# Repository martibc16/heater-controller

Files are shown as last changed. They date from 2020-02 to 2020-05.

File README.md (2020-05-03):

# heater-controller
A project to controll a domestic heating system with central heating and DHW

The heating system at home was initially controlled with simple relays that where commanded by thermostats. This had the problem that the integrated circulating pump would be on even the thermostats where off and so the actuators (that cut the flow of water to the circuit) where off. This is a picture of the heating room before:

<p align="center">
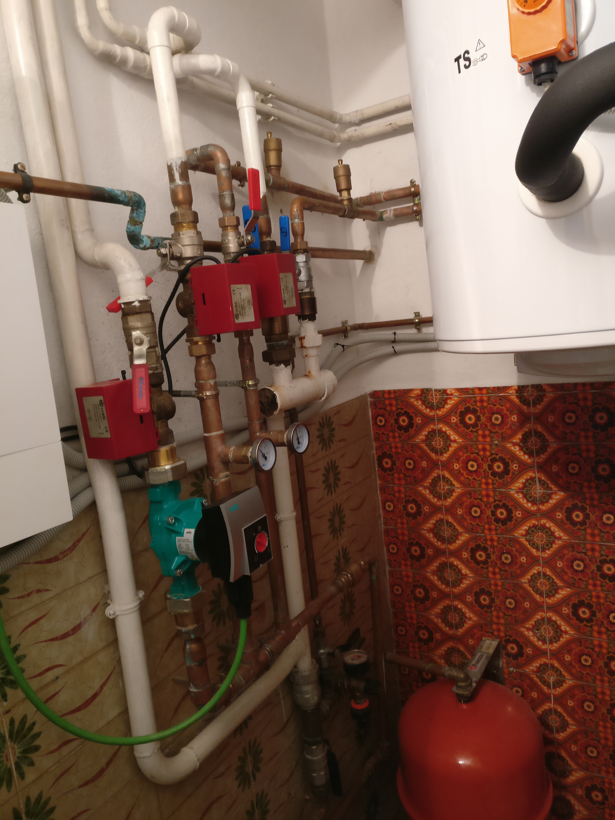
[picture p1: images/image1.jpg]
  
</p>

The controller is mounted on a DIN box and integrated in the electric panel.

The controller has:
* 6 optoisolated  digital outputs for connecting external relays
* 6 pull-down inputs
* I2C interface
* DS3231 RTC
* Atmega 2560 MCU

The result is this PCB:

<p align="center">
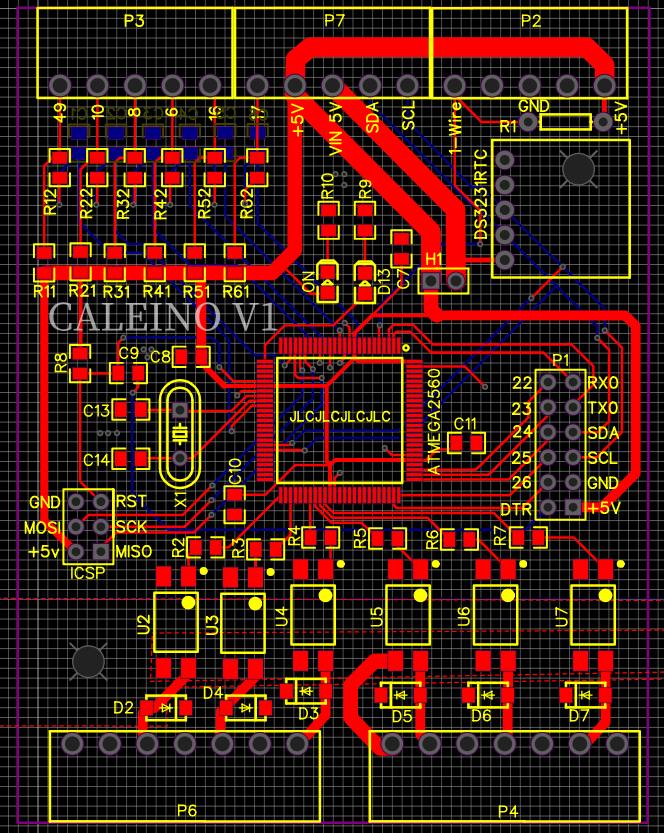
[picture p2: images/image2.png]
  
</p>
<p align="center">
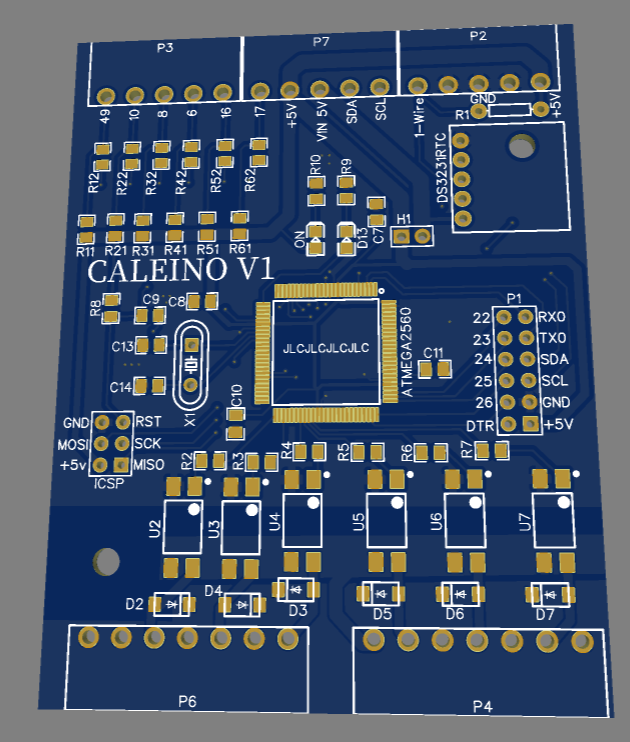
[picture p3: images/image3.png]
  
</p>

The analog temperature indicators were replaced by 1-wire sensors. To acomodate these sensors on the existing housing a 3D piece was needed to avoid the sensor being loose. This is a preview of the model:

<p align="center">
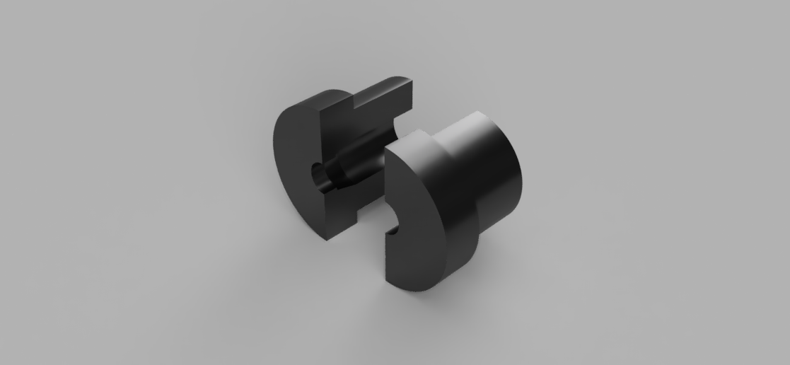
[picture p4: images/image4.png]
  
</p>
And this is the result when mounted with the sensor:
<p align="center">
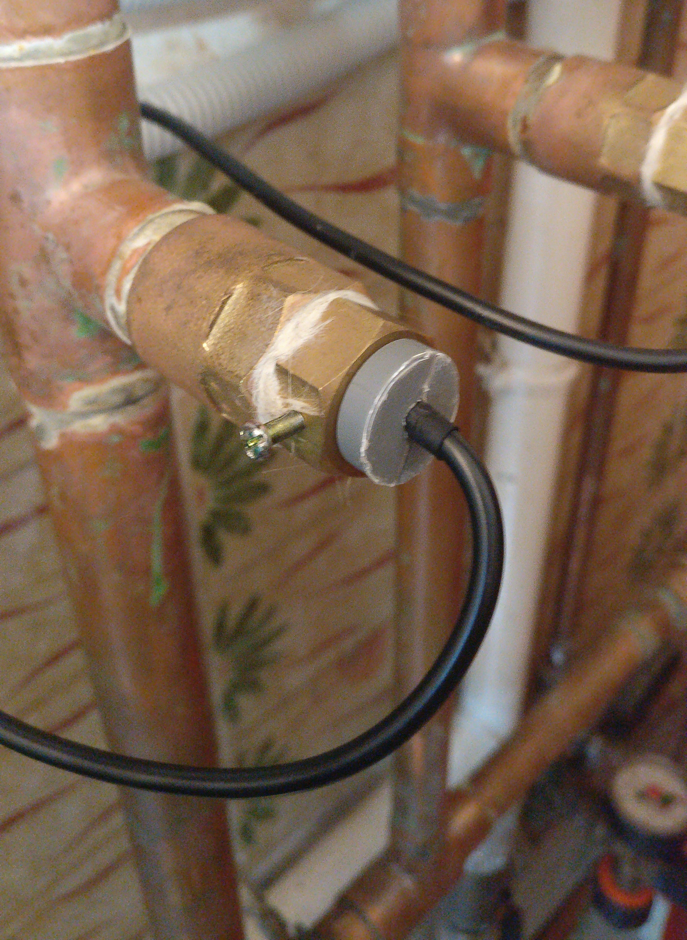
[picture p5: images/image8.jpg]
  
</p>

Finally, this is the photo of the finished model. Apart from the main PCB an auxiliary board has been created to acomodate the screen, the buttons and the programming interface (via FTDI connector). Through the screen you can control the status of the DHW supply (temperature and programmed state). It also gives information on the temperature of the DHW tank and the water temperature of the primary circuit (these are the sensors that are mounted with the 3D piece).
<p align="center">
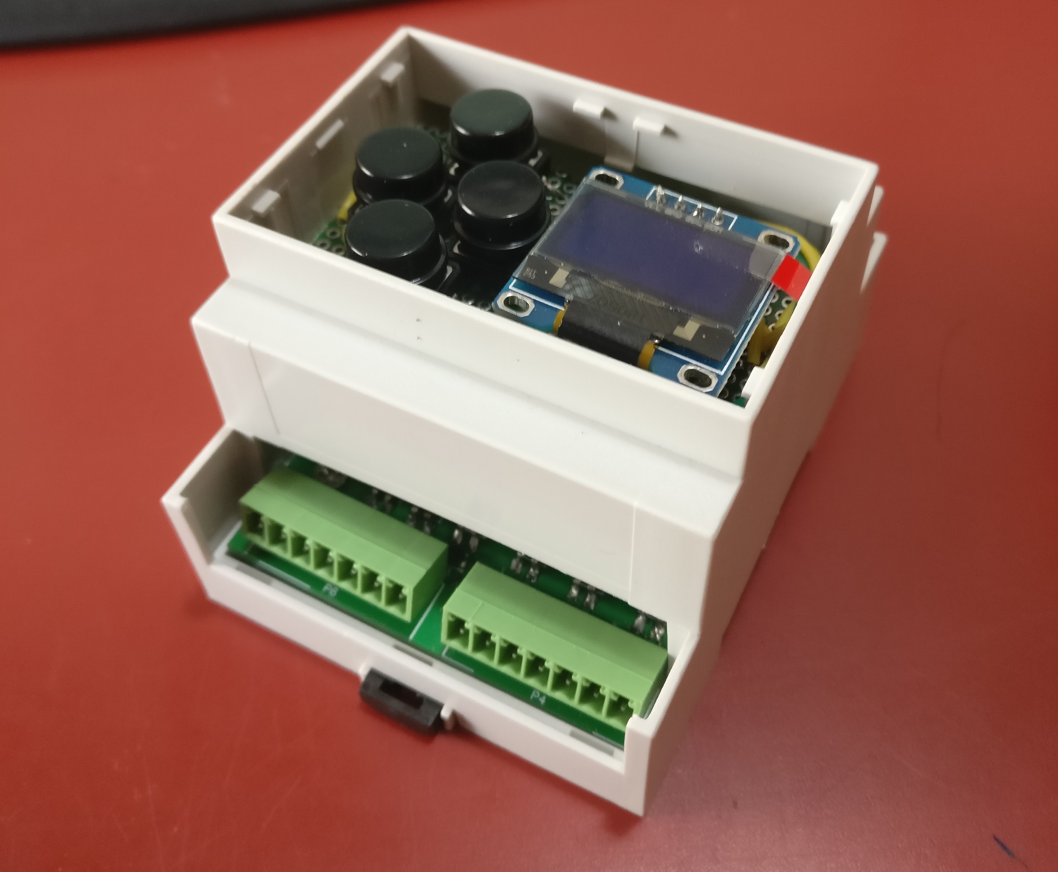
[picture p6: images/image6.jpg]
  
</p>
<p align="center">
  
</p>

The controller recieves the inputs from the thermostat on the dinning room (it's a normally open contact), the DHW tank temperature and the fireplace located on the dinning room (this is precisely the purpose of the green pump: To circulate the water from the fireplace into the main system) and the actuates on the ouputs which are connected to DIN relays. This gives the safest scenario since only the relays controll AC mains, the whole PCB works with low voltage DC (between 5V and 12V).

Here is a photo of the screen's controller:
<p align="center">
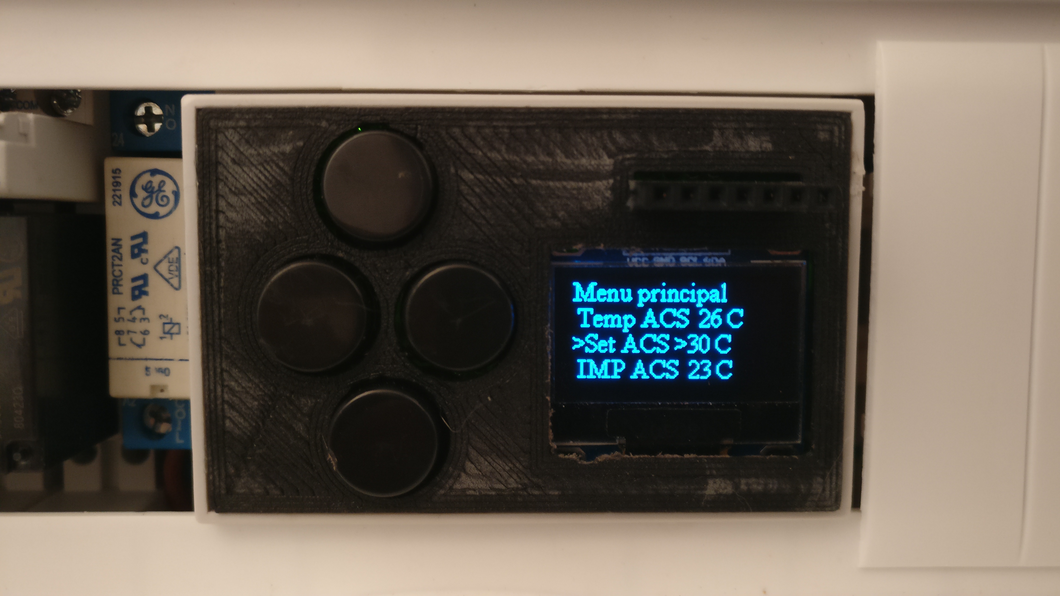
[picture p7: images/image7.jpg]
  
</p>

The programming was made using the Arduino IDE (See code folder)
The 3d model of the wire holder and the screen cover were made using Fusion360
The schematic and PCB files were made using EasyEDA software: https://easyeda.com/603mbastida/caleino-v4

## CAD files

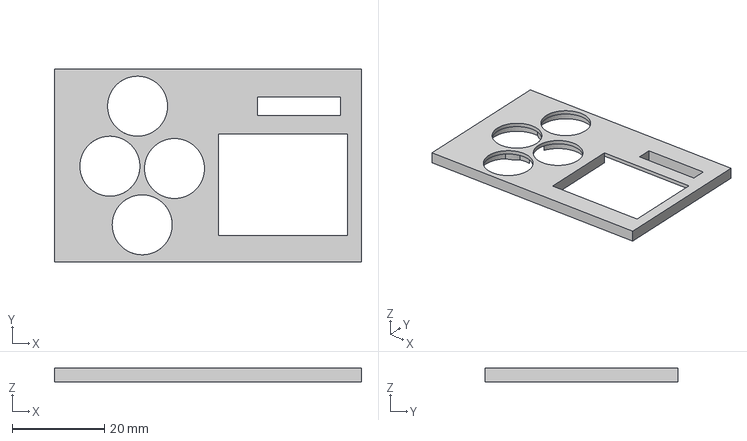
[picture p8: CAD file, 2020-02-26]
3d models/frontal_cover.step
66.5 x 41.7 x 3.00 mm

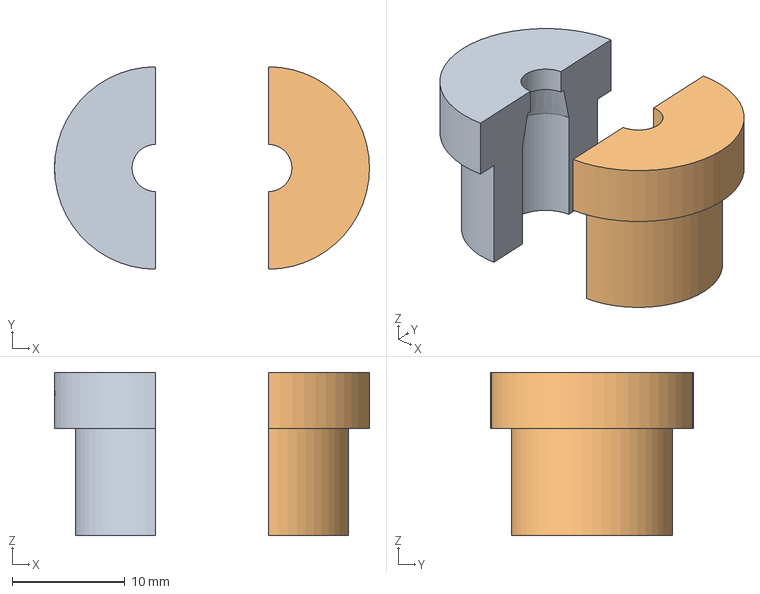
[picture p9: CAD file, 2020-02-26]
3d models/sensor_housing.step
28.0 x 18.0 x 14.5 mm

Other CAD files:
3d models/frontal_cover.f3d
3d models/sensor_housing.f3d

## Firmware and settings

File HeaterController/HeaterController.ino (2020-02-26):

#include "config.h"
#include "Menu.h"
#include "LogicaCale.h"


void setup() {
  Serial.begin(9600);

  EEPROM.get(0, tSetACS);
  EEPROM.get(20, deltaT);
  refreshEeprom = millis();

  if (tSetACS > 80)
    tSetACS = 45;

  if (deltaT > 20)
    deltaT = 4;

  setSyncProvider(RTC.get);   // the function to get the time from the RTC
  if (timeStatus() != timeSet)
    Serial.println("Unable to sync with the RTC");
  else
    Serial.println("RTC has set the system time");

  pinMode(PINACS, OUTPUT);
  pinMode(PINCALE, OUTPUT);
  pinMode(PINFAT, OUTPUT);
  pinMode(PINCALDERA, OUTPUT);
  pinMode(PINTERMOSTAT, INPUT_PULLUP);
  pinMode(PINBOMBACIR, INPUT_PULLUP);
  pinMode(PINTERMOFAT, INPUT_PULLUP);
  pinMode(A6, INPUT);
  termostatActiu = false;
  canviEstat = false;
  ACSON = false;

  sensors.begin();
  sensors.setResolution(ACS, resolution);

  sensors.setWaitForConversion(false);
  sensors.requestTemperatures();

  delayInMillis = 750 / (1 << (12 - resolution));
  lastTempRequest = millis();

  
    Alarm.alarmRepeat(10, 0, 0, onProg);
    Alarm.alarmRepeat(13, 30, 0, offProg);
    Alarm.alarmRepeat(dowMonday , 16, 0, 0, onProg);
    Alarm.alarmRepeat(dowTuesday , 16, 0, 0, onProg);
    Alarm.alarmRepeat(dowWednesday , 16, 0, 0, onProg);
    Alarm.alarmRepeat(dowThursday , 16, 0, 0, onProg);
    Alarm.alarmRepeat(dowFriday , 16, 0, 0, onProg);
    Alarm.alarmRepeat(dowSaturday , 16, 0, 0, onProg);
    Alarm.alarmRepeat(19, 30, 0, offProg);
    Alarm.alarmRepeat(23, 0, 0, offProg);
  
 // newAlarm(9, 30, 1, true);


  joystickBtns.begin();
  Wire.begin();
  oled.begin(&Adafruit128x64, OLED_I2C_ADDRESS); //check config
  oled.setFont(menuFont);
  oled.clear();
  tempsStandby = millis();

#if RST_PIN >= 0
  oled.begin(&Adafruit128x64, I2C_ADDRESS, RST_PIN);
#else // RST_PIN >= 0
  oled.begin(&Adafruit128x64, I2C_ADDRESS);
#endif // RST_PIN >= 0


  mainMenu[0].disable();
  mainMenu[2].disable();
  mainMenu[3].disable();
  mainMenu[5].disable();

  Wire.setClock(400000);
}

float timre;
void loop() {
  timre = millis();
  readSensors();

  storeInEEPROM();

  checkForStateChanges();

  nav.poll();
  Alarm.delay(1);//simulate a delay when other tasks are done

  /**********Used for debugging************/
  /*Serial.print(hour());
    Serial.print("\t");
    Serial.print(minute());
    Serial.print("\t");
    Serial.print(second());
    Serial.print("\t");*/
    Serial.print(progACS);
    Serial.print("\t AutoProg:");
    Serial.print(autoProgACS);
    Serial.print("\t tACS: ");
    Serial.print(tACS);
    Serial.print("\t");
    Serial.print(tSetACS);
    Serial.print("\t");
    Serial.print(tSetACS+deltaT);
    Serial.print("\t ACSon:");
    Serial.println(ACSON);
  /**********************/


  if (digitalRead(BTN_SEL) == LOW || digitalRead(BTN_UP) == LOW || digitalRead(BTN_DOWN) == LOW || digitalRead(BTN_ESC) == LOW)
  {
    tempsActiu = millis();
    oled.ssd1306WriteCmd(SSD1306_DISPLAYON);
  }
  else if (millis() - tempsActiu > 60000)
    oled.ssd1306WriteCmd(SSD1306_DISPLAYOFF);

}

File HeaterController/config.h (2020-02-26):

/*config.h*/

/* List of Supported Fonts

  Arial14,
  Arial_bold_14,
  Callibri11,
  Callibri11_bold,
  Callibri11_italic,
  Callibri15,
  Corsiva_12,
  fixed_bold10x15,
  font5x7,    //Do not use in LARGE_FONT, can use as default font
  font8x8,
  Iain5x7,    //Do not use in LARGE_FONT, can use as default font
  lcd5x7,     //Do not use in LARGE_FONT, can use as default font
  Stang5x7,   //Do not use in LARGE_FONT, can use as default font
  System5x7,  //Do not use in LARGE_FONT, can use as default font
  TimesNewRoman16,
  TimesNewRoman16_bold,
  TimesNewRoman16_italic,
  utf8font10x16,
  Verdana12,
  Verdana12_bold,
  Verdana12_italic,
  X11fixed7x14,
  X11fixed7x14B,
  ZevvPeep8x16

*/


/*
   Incloem llibreries
*/

#include <menu.h>

#include <EEPROM.h>

#include <TimeLib.h>
#include <TimeAlarms.h>
#include <DS3232RTC.h>

#include <OneWire.h>
#include <DallasTemperature.h>
#include <Wire.h>

#include "SSD1306Ascii.h"
#include "SSD1306AsciiWire.h"
#include <menu.h>
#include <menuIO/SSD1306AsciiOut.h>
#include <menuIO/keyIn.h>


/*
   Definim sortides a optoacopladors
*/
#define PINACS 33
#define PINCALE 37
#define PINFAT 32 //actuador Foc a Terra
#define PINCALDERA 41

/*
 * Definim entrades digitals
 */
#define PINTERMOSTAT 49
#define PINBOMBACIR 8
#define PINTERMOFAT 10


/*
   Definim variables calefaccio
*/
 short int tACS ;
unsigned short int tSetACS;
unsigned short int deltaT; //hysteresis for the DHW tank
bool ACSON;
unsigned short int progACS = 0; //0 auto, 1 on, 2 on-perm, 3 off-per
bool autoProgACS=false; //true-on false-off
short int tTAIACS;
short int tTAICal;
bool termostatActiu;
bool FATactiu;
bool canviEstat;

unsigned short int hora, minut, dia, mes;
unsigned short int any = 2019;

unsigned long int tempsStandby;
unsigned long int refreshEeprom;

/*
   OneWire Definitions
*/
const int pinDatosDQ = 5; //onewire
OneWire oneWireBus(pinDatosDQ);
DallasTemperature sensors(&oneWireBus);
DeviceAddress TAICal = {0x28, 0xFF, 0x6A, 0x1B, 0x32, 0x18, 0x02, 0xFF};
DeviceAddress TAIACS = {0x28, 0xD6, 0x08, 0x30, 0x0A, 0x00, 0x00, 0x74};
DeviceAddress ACS = {0x28, 0x24, 0xD2, 0x45, 0x92, 0x11, 0x02, 0x3B};
int  resolution = 12;
unsigned long lastTempRequest = 0;
int  delayInMillis = 0;

float RawHighACS = 100.37;
float RawLowACS = 0.44;
float RawHighTAIACS = 101.31;
float RawLowTAIACS = 1.06;
float RawHighTAICal=100;
float RawLowTAICal=0;

float ReferenceHigh = 99.8;
float ReferenceLow = 0;
float ReferenceRange = ReferenceHigh - ReferenceLow;

unsigned long tempsActiu=0;

#define OLED_I2C_ADDRESS 0x3C     
#define I2C_ADDRESS 0x3C
SSD1306AsciiWire oled;

// Define proper RST_PIN if required.
#define RST_PIN -1


/*
   Define your font from the list.
   Default font: lcd5x7
   Comment out the following for using the default font.
*/
#define LARGE_FONT TimesNewRoman16

//Navigate buttons
#define BTN_SEL     25                 // Select button
#define BTN_UP      24                 // Up Button
#define BTN_DOWN    26                 // Down Button
#define BTN_ESC     23                 // Exit Button
// Comment the following to disable internal pullup for Navigate buttons
#define NAV_BUTTONS_INPUT_PULLUP

#define TOTAL_NAV_BUTTONS 4       // Total Navigation Button used



#define MAX_DEPTH 2

#ifdef LOC
// #define LARGE_FONT
#define INV
#endif

/*Do not change the values(recomended)*/
#ifdef LARGE_FONT
#define menuFont LARGE_FONT
#define fontW 8
#define fontH 16
#else
// #define menuFont System5x7
#define menuFont lcd5x7
#define fontW 5
#define fontH 8
#endif
